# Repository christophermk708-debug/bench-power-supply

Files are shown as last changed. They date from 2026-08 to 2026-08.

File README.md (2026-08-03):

# bench-power-supply
# Adjustable Bench Power Supply

A from-scratch benchtop power supply: adjustable 1.4–11.9 V buck-regulated main output with live voltage/current display, plus fixed 5 V and 3.3 V rails. Designed in KiCad, fabricated by JLCPCB, hand-assembled, and brought up with a staged test procedure. 

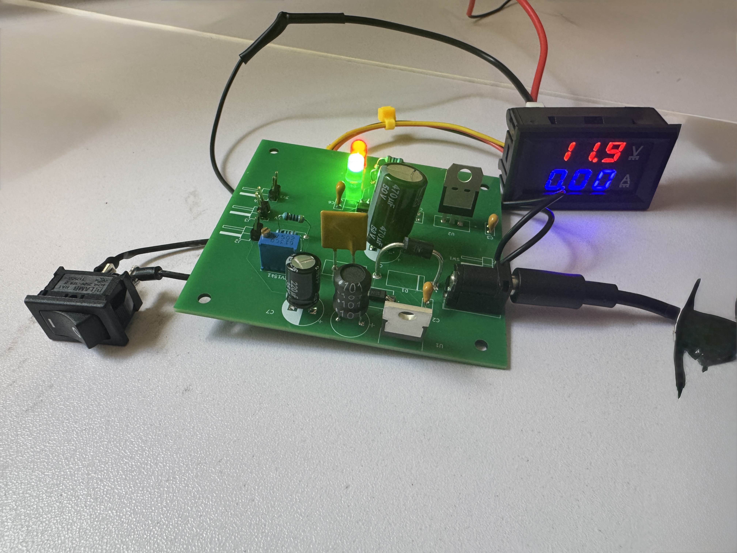
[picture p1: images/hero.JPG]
Assembled supply powering a load


## Specifications (measured)

| Parameter | Value |
|---|---|
| Input | 12 V DC barrel jack (center-positive, regulated) |
| Adjustable output | **1.4 – 11.9 V** (25-turn trimmer), ~2 A class |
| Fixed rails | 5.0 V (L7805) and 3.3 V (AMS1117) on headers |
| Metering | Panel voltmeter/ammeter on the adjustable output |
| Protection | Reverse-polarity Schottky (1N5822), 3 A resettable PTC fuse, per-rail decoupling |

## Design

- **LM2596-ADJ buck converter** for the main rail-switching regulation chosen over linear for efficiency at multi-amp loads. Output set by a feedback divider: `Vout = 1.23 × (1 + R_upper/R_lower)`, with a 25-turn trimmer as the adjustable element.
- **Fixed rails cascade from the buck's input**: the 7805 drops 12 V→5 V and the AMS1117 is fed *from the 5 V rail* rather than raw input to minimize dissipation.
- **Layout follows switching-supply practice**: the LM2596/inductor/catch-diode/capacitor loop is clustered tightly to minimize the switching current loop.

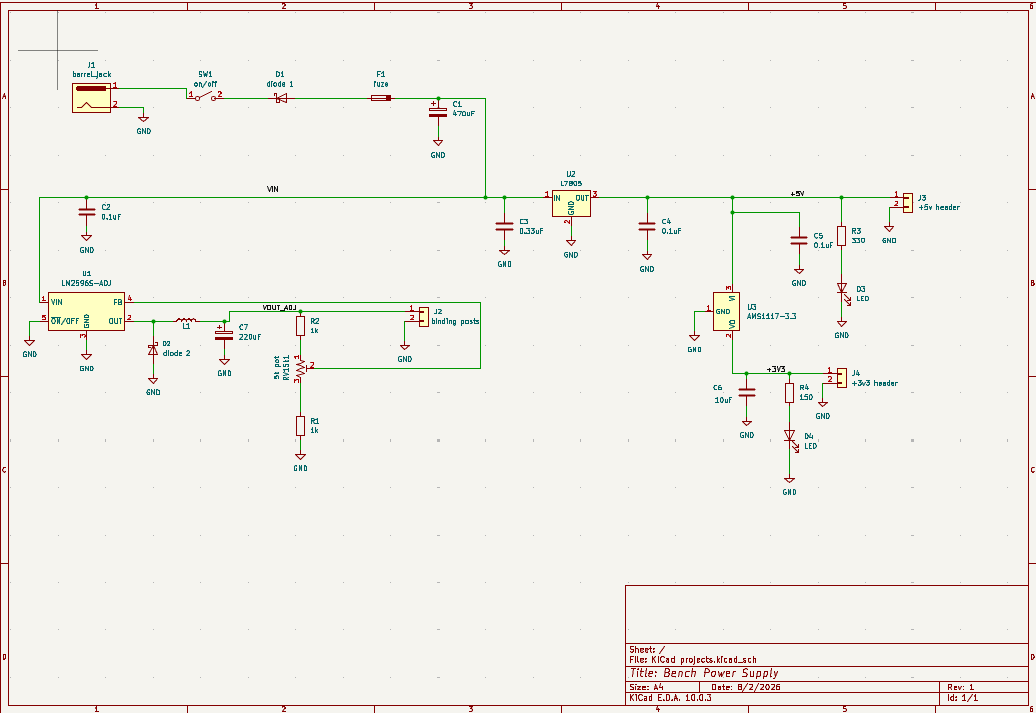
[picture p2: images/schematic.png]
Schematic

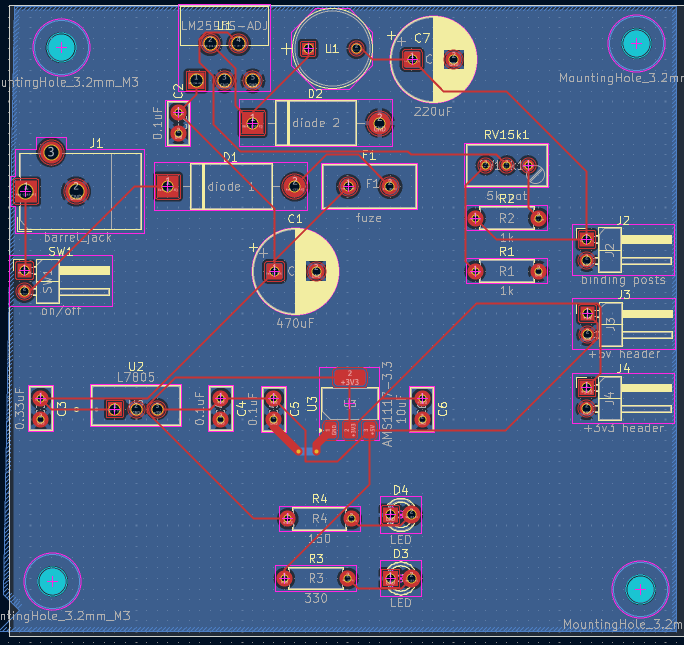
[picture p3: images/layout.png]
PCB layout

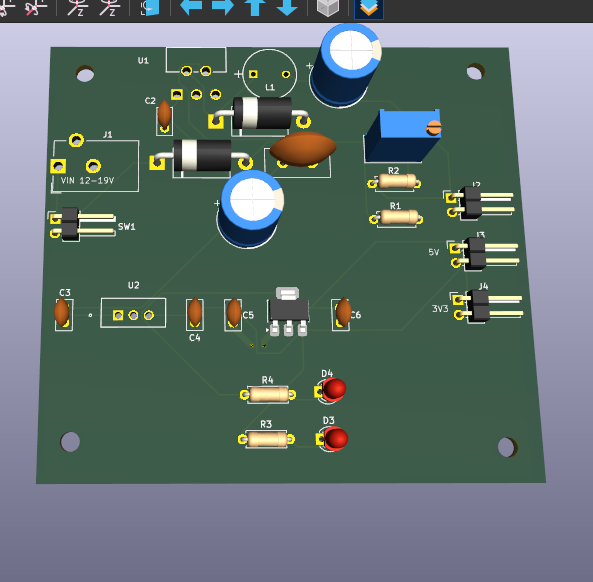
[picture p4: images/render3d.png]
3D render


## Rev A findings — what the first board taught me

Every one of these was found by measurement during bring-up.

1. **D1 (reverse-polarity diode) was oriented backwards *in the schematic*.** The silkscreen reproduced the error, so the assembled board matched the design and this blocked all input power. Found by voltage tracing: ~12 V on the jack side of D1, ~1 V after it. Invisible to DRC and 3D review because the error was electrical, not mechanical. Fixed by desoldering and flipping the part.
2. **Maximum output was limited to 8.6 V by the feedback divider**, not by input headroom. Derived from the regulation equation: with R_lower = 1 kΩ, max Vout = 1.23 × (1 + 6k/1k) ≈ 8.6 V. Reworked R1 from 1 kΩ → 470 Ω on-board, raising the measured maximum to 11.9 V.
3. **J1 barrel jack footprint was placed rotated 180°** — the connector opening faced into the board. Resolved by flipping the 

## Bring-up lessons 

- A "12 V" wall adapter measured **25 V with no load**  it was an unregulated transformer type that only reaches nameplate under rated current. Replaced with a regulated switching adapter; my acceptance test is now a bare-plug measurement before any adapter touches a board.
- Mid-debug, **every reading came in almost exactly 2× high**  input, both fixed rails, even a USB 5 V reference. The multimeter's factory-included battery was dying, skewing its reference. Verified against known references (fresh AA cell, USB 5 V, the panel meter) before condemning any hardware. Lesson: when every measurement is wrong by the same factor, suspect the instrument first.

## Bring-up procedure

Staged and gated: visual inspection → continuity short-hunt on every rail  → adapter verification  → first power with no load, rail-by-rail measurement → potentiometer sweep across the full range → panel-meter cross-calibration against the DMM → first real load. No stage proceeds until the previous one passes.

## Rev B changes

- D1 orientation corrected in schematic
- J1 footprint rotated 180°
- R1 = 470 Ω for full output range

## Files

- `kicad/` — schematic and PCB source
- `gerbers/` — fabrication files as sent to JLCPCB
- `images/` — renders and build photos

## First real job

This supply's first load was my PID temperature controller — the panel ammeter visibly tracks the controller's PWM duty as it regulates.

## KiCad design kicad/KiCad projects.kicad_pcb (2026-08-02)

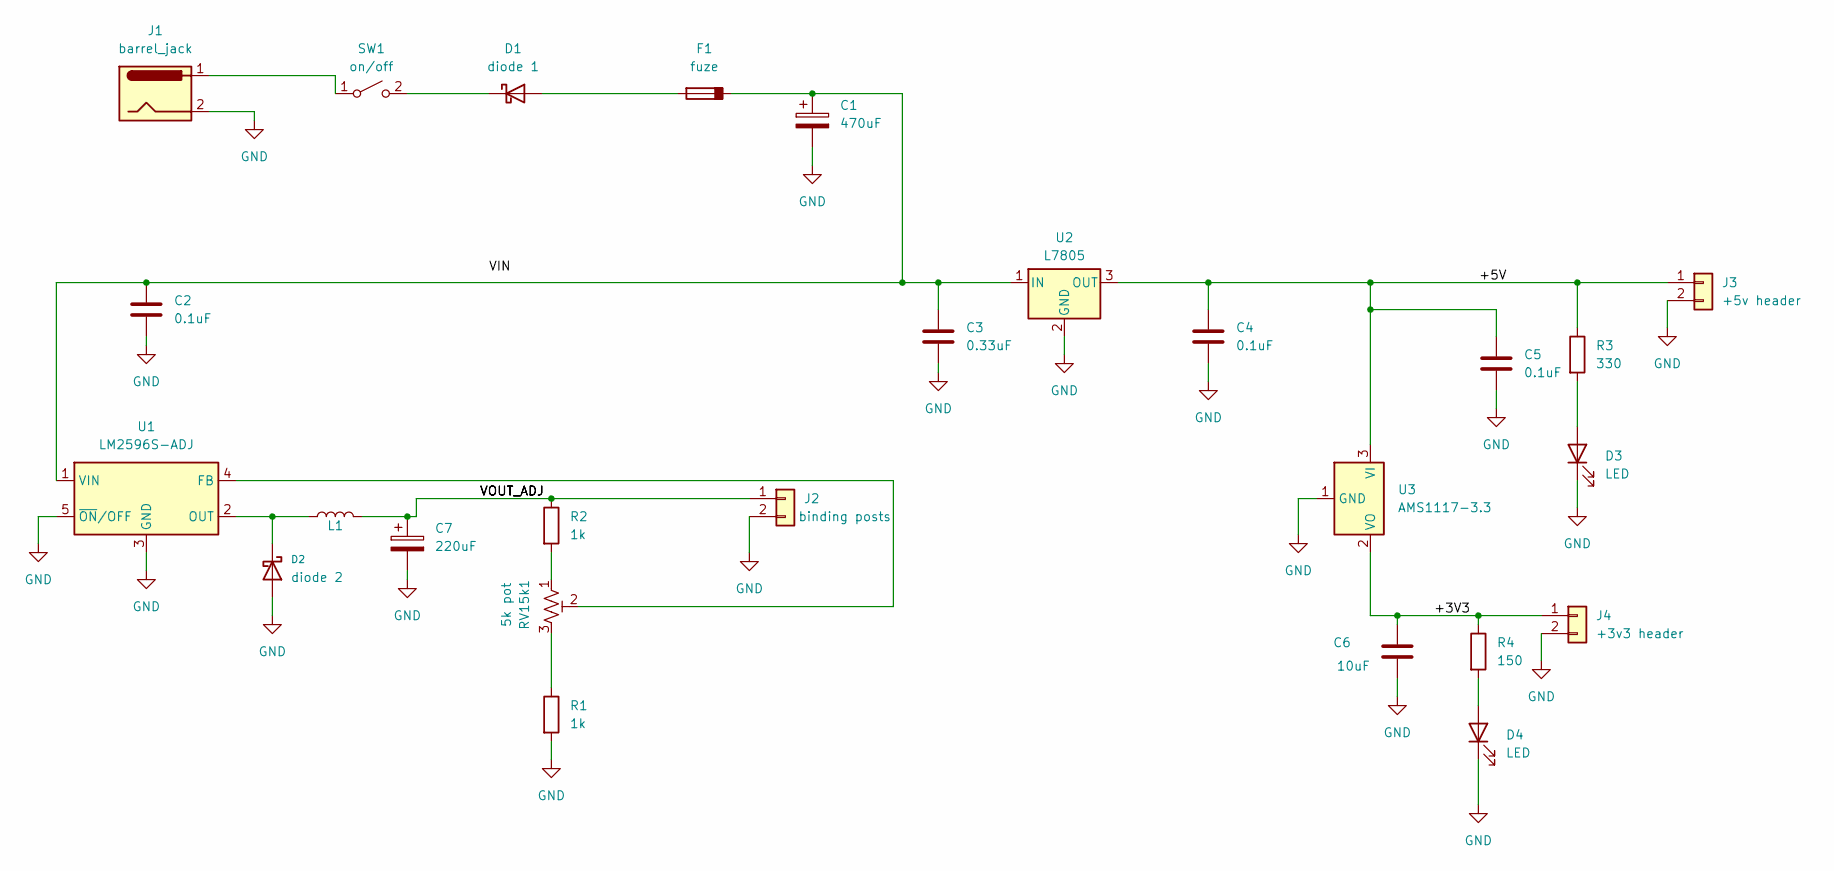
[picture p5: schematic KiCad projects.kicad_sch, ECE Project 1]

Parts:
C1: 470uF; CP_Radial_D10.0mm_P5.00mm
C2, C4, C5: 0.1uF; C_Disc_D5.0mm_W2.5mm_P2.50mm
C3: 0.33uF; C_Disc_D5.0mm_W2.5mm_P2.50mm
C6: 10uF; C_Disc_D5.0mm_W2.5mm_P2.50mm
C7: 220uF; CP_Radial_D10.0mm_P5.00mm
D1: diode 1; P2_DO-201
D2: diode 2; P2_DO-201
D3, D4: LED; LED_D3.0mm
F1: fuze; C_Disc_D11.0mm_W5.0mm_P5.00mm
J1: barrel_jack; BarrelJack_CUI_PJ-102AH_Horizontal
J2: binding posts; PinHeader_1x02_P2.54mm_Horizontal
J3: +5v header; PinHeader_1x02_P2.54mm_Horizontal
J4: +3v3 header; PinHeader_1x02_P2.54mm_Horizontal
L1: L; IND_BOURNS_RLB0914
R1, R2: 1k; R_Axial_DIN0207_L6.3mm_D2.5mm_P7.62mm_Horizontal
R3: 330; R_Axial_DIN0207_L6.3mm_D2.5mm_P7.62mm_Horizontal
R4: 150; R_Axial_DIN0207_L6.3mm_D2.5mm_P7.62mm_Horizontal
RV15k1: 5k pot; Potentiometer_Bourns_3296W_Vertical
SW1: on/off; PinHeader_1x02_P2.54mm_Horizontal
U1: LM2596S-ADJ; T05D
U2: L7805; TO-220_STM
U3: AMS1117-3.3; SOT-223-3_TabPin2

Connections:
/+3V3: C6.1, J4.1, R4.1, U3.2 (VO)
/+5V: C4.1, C5.1, J3.1, R3.1, U2.3 (OUT), U3.3 (VI)
GND: C1.2, C2.2, C3.2, C4.2, C5.2, C6.2, C7.2, D2.2 (A), D3.1 (K), D4.1 (K), J1.2, J2.2, J3.2, J4.2, R1.2, U1.3 (GND), U1.5 (~ON/OFF), U2.2 (GND), U3.1 (GND)
unnamed: D1.2 (A), F1.2
unnamed: D1.1 (K), SW1.2 (B)
unnamed: D2.1 (K), L1.1, U1.2 (OUT)
unnamed: D3.2 (A), R3.2
unnamed: D4.2 (A), R4.2
unnamed: C7.1, J2.1, L1.2, R2.1
unnamed: R1.1, RV15k1.3
unnamed: R2.2, RV15k1.1
unnamed: J1.1, SW1.1 (A)
unnamed: RV15k1.2, U1.4 (FB)
unnamed: C1.1, C2.1, C3.1, F1.1, U1.1 (VIN), U2.1 (IN)

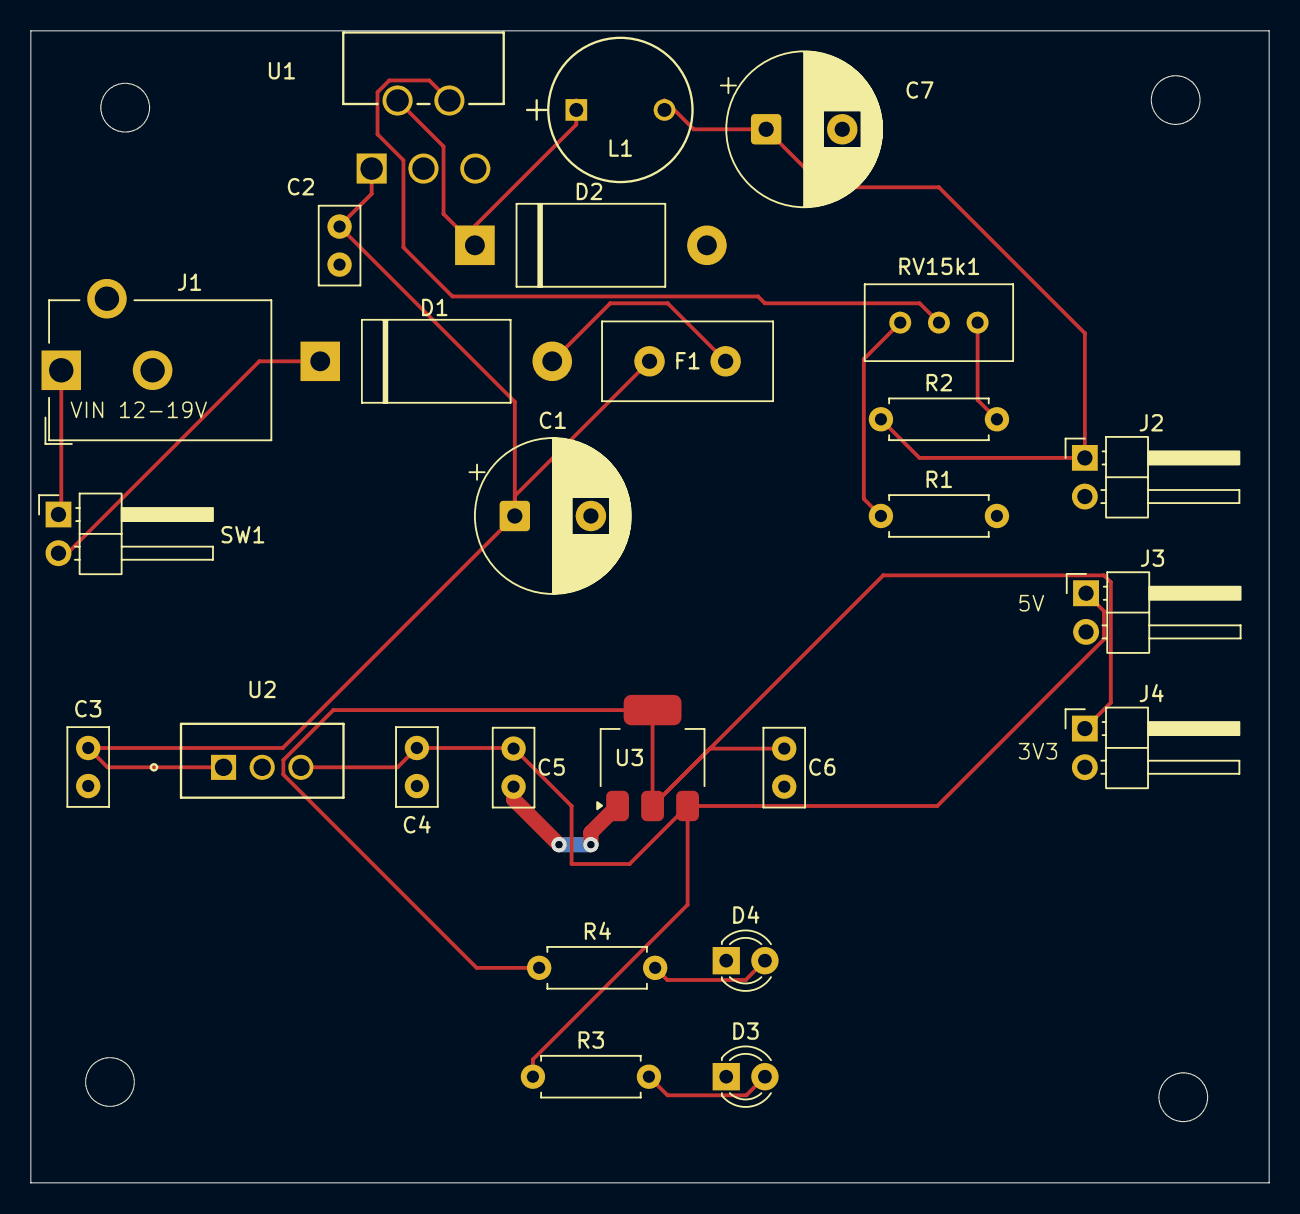
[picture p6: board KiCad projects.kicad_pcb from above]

Board: 2 copper layers, 81.3 x 75.7 mm, 26 parts (0 on the bottom side), 14 nets.
